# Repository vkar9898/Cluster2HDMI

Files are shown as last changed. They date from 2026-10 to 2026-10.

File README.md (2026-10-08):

# Cluster2HDMI
A project dedicated to utilising a 7 inch LCD panel as a standalone monitor via a HDMI-parallel RGB converter and a Pico 2 fitted on a custom PCB

I have been reverse engineering a 7" LCD panel that I pulled out of a vehicle dashboard, in hopes of using it as a standalone monitor. So far I have mapped every pin on the 45-pin video connector, and the next step is designing and ordering a PCB to drive it.

<p align="center">
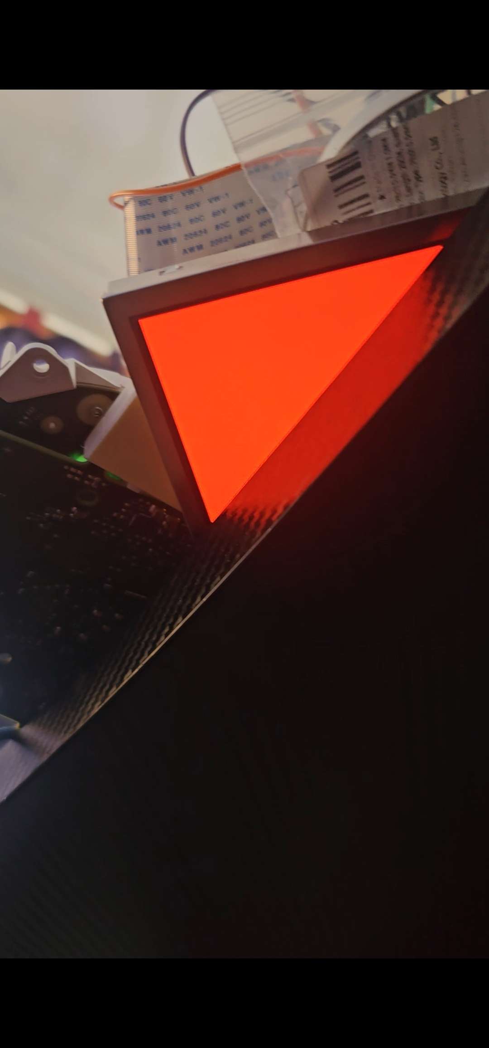
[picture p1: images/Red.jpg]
  
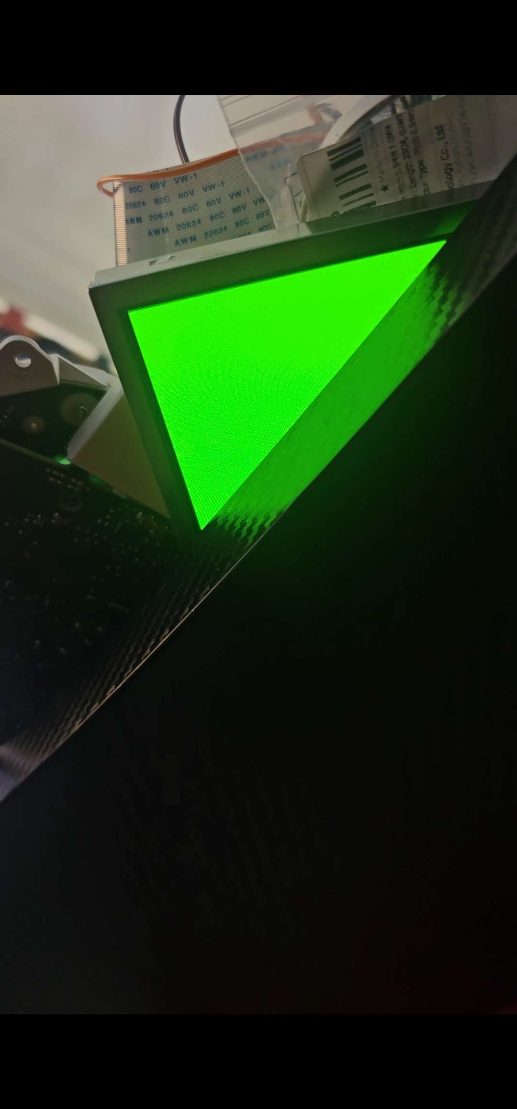
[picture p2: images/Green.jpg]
  
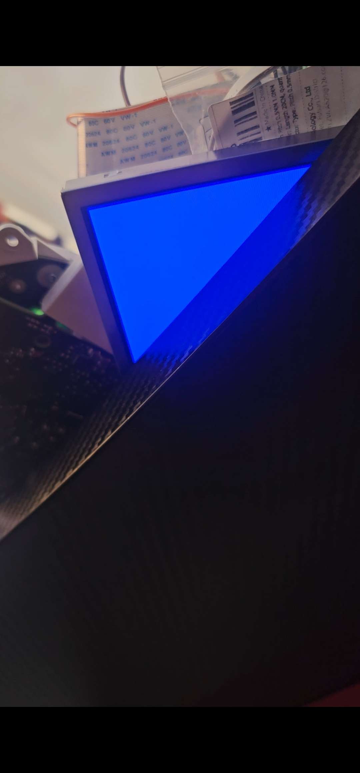
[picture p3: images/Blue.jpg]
  
</p>

<p align="center">
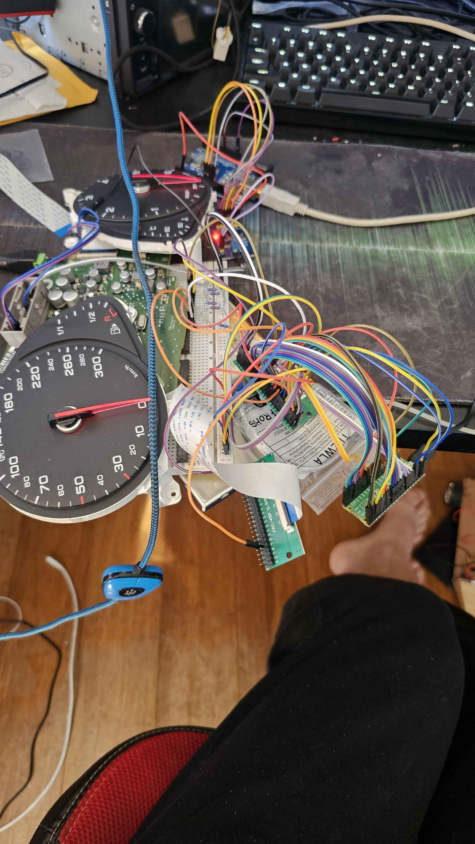
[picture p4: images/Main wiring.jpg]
  
</p>

## Why I made this

This panel comes from an Audi Q7 instrument cluster (dashboard). Prior to this, I was able to control the entire dashboard via the CAN protocol. After that, I had the dream of being able to control the LCD entirely independently. I have always found it interesting reverse engineering things and making them work how I want, so I believed this project would be a great start, and so far it has.

## What it does

In the end, I aim to have this work as a standalone monitor, working via converting HDMI to parallel RGB, with a 12V PSU powering both the panel and its backlight, and rerouting specific pins to the panel, in order to make it work.

## How it works

From my computer, a HDMI cable will be plugged into a custom PCB, where it is converted to parallel RGB, before the video-specific pins (RGB, HSYNC, VSYNC, PCLK, etc.) will be routed to the correct pins connected to the panel. A Pico 2 will replicate the SPI setup commands the dashboard originally sends to the panel, and control the backlight brightness. The 12V supply will also power the panel's logic through a 3.3V regulator, and the backlight through a constant-current LED driver.

## Reverse engineering the panel

Originally, I had tried to search for datasheets available for my panel, but this was to no avail. There is not a single public datasheet available on the internet, which meant I had to reverse engineer it myself entirely. I began by connecting the dashboard's ribbon to one FFC breakout board and the panel's flex to another, with jumper wires between them, so I could probe every pin for continuity and voltage with a multimeter while the panel was running. Many problems were met here, more in the [journal](JOURNAL.md).

### Pin map (45-pin, 0.5 mm FPC)

Numbers are the breakout board labels.

| Label | Function | Notes |
|---|---|---|
| 1, 2, 13, 22, 31, 33, 37, 44, 45 | Ground | |
| 3 | Unknown | 1.5 kΩ pull-down to ground on the cluster side |
| 4, 38 | Power in | Supplied by the cluster (voltage to be confirmed) |
| 5–12 | Blue B0–B7 | 5 = least significant bit |
| 14–21 | Green G0–G7 | 14 = least significant bit |
| 23–30 | Red R0–R7 | 23 = least significant bit |
| 32 | PCLK | Pixel clock |
| 34 | HSYNC | |
| 35 | VSYNC | |
| 36 | DE | Data enable |
| 39, 43 | Not connected | Function unknown |
| 40 | SPI data (MOSI) | Setup commands |
| 41 | SPI chip select | Active low |
| 42 | SPI clock | |

### Video timing (measured from the cluster)

| | Value |
|---|---|
| Resolution | 800 × 480 |
| Pixel clock | ~26.8 MHz (cluster), 25 MHz (my Pico driver) |
| Horizontal | HSYNC 10 px, back porch 6 px, active 800 px, front porch 106 px, total 922 px |
| Vertical | active 480 lines, front porch 8, VSYNC 4, back porch 8, total 500 lines |
| Refresh rate | ~58 Hz (cluster), ~54 Hz (Pico) |
| Sync polarity | HSYNC and VSYNC active low, DE active high |

### SPI setup sequence

3-wire SPI, mode 0, MSB first, ~500 kHz, chip select active low.
Starts ~25 ms after video starts. Without it the panel stays black.

| Step | Bytes (hex) | Delay after |
|---|---|---|
| 1 | 1B 50 00 | 2.15 ms |
| 2 | 1D 5C 00 | 2.15 ms |
| 3 | 10 00 | 2.15 ms |
| 4 | 08 80 | ~125.6 ms |
| 5 | 14 80 | |

The cluster repeats the whole set every ~545.6 ms. What each register does is unknown.

## Current status

Currently, I am able to display full-screen solid colours on the panel from the Pico: red, green and blue, as well as other colours such as cyan, magenta, white, etc. (6 bits per colour). The panel's power and backlight still come from the cluster. Next is to properly power the panel via my own power supply from a custom PCB, and be able to use it as a standalone monitor connected to my computer via HDMI.

## Wiring (current test setup)

Breakout A = panel side, Breakout B = cluster side. Numbers are the breakout labels.

### Timing and SPI

| Pico 2 | Breakout A | Signal |
|---|---|---|
| GP0 | 32 | PCLK |
| GP1 | 36 | DE |
| GP2 | 34 | HSYNC |
| GP27 | 35 | VSYNC |
| GP28 | — | Not connected (used internally by the Pico) |
| GP21 | 42 | SPI clock |
| GP22 | 40 | SPI data (MOSI) |
| GP26 | 41 | SPI chip select |
| GND | Ground rail | Ground |

### Colour data (top 6 bits of each colour)

| Colour | Bit | Breakout A | Pico 2 |
|---|---|---|---|
| Blue | B2 | 7 | GP5 |
| Blue | B3 | 8 | GP6 |
| Blue | B4 | 9 | GP7 |
| Blue | B5 | 10 | GP8 |
| Blue | B6 | 11 | GP3 |
| Blue | B7 | 12 | GP9 |
| Green | G2 | 16 | GP12 |
| Green | G3 | 17 | GP13 |
| Green | G4 | 18 | GP14 |
| Green | G5 | 19 | GP4 |
| Green | G6 | 20 | GP15 |
| Green | G7 | 21 | GP10 |
| Red | R2 | 25 | GP18 |
| Red | R3 | 26 | GP19 |
| Red | R4 | 27 | GP20 |
| Red | R5 | 28 | GP11 |
| Red | R6 | 29 | GP16 |
| Red | R7 | 30 | GP17 |

### Resistors to ground

| Breakout A | Resistor | Why |
|---|---|---|
| 3 | 1 kΩ | Stands in for the cluster's 1.5 kΩ pull-down |
| 5, 6 | 2.2 kΩ each | Blue B0–B1 held low (unused) |
| 14, 15 | 2.2 kΩ each | Green G0–G1 held low (unused) |
| 23, 24 | 2.2 kΩ each | Red R0–R1 held low (unused) |

### Cluster to panel (breakout B → breakout A)

| Connection | Purpose |
|---|---|
| B4 → A4 | Panel power from the cluster |
| B38 → A38 | Panel power from the cluster |
| A1, 2, 13, 22, 31, 33, 37, 44, 45 → ground rail | Panel grounds |
| B1, 22, 44 → ground rail | Cluster ground |
| A39, A43 | Left unconnected |
| 10-pin backlight ribbon | Stays plugged into the cluster |

Power order: cluster on first, then plug in the Pico.

## Hardware

Coming once PCB is designed

## Firmware

Currently, the Pico code is MicroPython, written and run through Thonny. It generates the timing signals (PCLK, HSYNC, VSYNC, DE) using the Pico's PIO hardware, sends the SPI setup sequence, and controls the red, green and blue bits. The test firmware was written with help from Claude (AI). In the future, it will only be doing the SPI sequence and backlight control on the PCB, as the HDMI-parallel RGB converter will be responsible for the timing and colour bits. Code can be found [here](Firmware)

## How to flash

1. Holding BOOTSEL, plug in your Pico, and drag the [MicroPython .uf2 file](https://micropython.org/download/RPI_PICO2/) onto the drive that appears.
2. Open Thonny and choose the Pico as the interpreter, before saving the [firmware](Firmware) file onto the Pico as "main.py". After this, it'll run automatically on power-up. 
3. Turn on the cluster first, then turn on the Pico. You are done!

## Known issues

* Pins 3, 39 and 43's functions are unknown
* Exactly what each SPI register does is unknown, but easily replicable
* Unknown whether the panel needs SPI commands repeated
* Panel's power and backlight still come from the cluster
* 10-pin backlight connector hasn't been reverse-engineered yet
* Pico test driver uses 6 bits per colour, not 8, and can only show solid colours
* Loose wiring can cause unexpected disconnections

## Building one yourself

Coming once the PCB is finished.

## Bill of materials

| Part | Qty | Est. cost (AUD) | Link | Description |
|---|---|---|---|---|
| **Main parts** | | | | |
| Adafruit TFP401 HDMI/DVI decoder (no touch) | 1 | 55 | [Adafruit](https://www.adafruit.com/product/2219) | Converts HDMI to 24-bit parallel RGB |
| PCB fabrication + assembly of FPC connectors | 1 order | 30–50 | [JLCPCB](https://jlcpcb.com) | Custom adapter/driver board |
| 12 V power supply | 1 | 33 | [Amazon](https://www.amazon.com.au/dp/B0CRGJ15HS) | Main power input |
| Raspberry Pi Pico 2 | 1 | owned | [Raspberry Pi](https://www.raspberrypi.com/products/raspberry-pi-pico-2/) | SPI setup commands + backlight control |
| Audi Q7 4M0 920 781 A instrument cluster | 1 | owned | [eBay](https://www.ebay.co.uk/itm/177800811902) | Source of the 7" 800×480 LCD panel |
| **Connectors** | | | | |
| Hirose FH34SRJ-45S-0.5SH 45-pin FPC connector | 2 | 5 | [LCSC C3170034](https://www.lcsc.com/product-detail/C3170034.html) | Panel connector |
| XUNPU FPC-05FB-40PH20 40-pin FPC connector | 2 | 5 | [LCSC C2856837](https://www.lcsc.com/product-detail/C2856837.html) | TFP401 ribbon connector |
| 40-pin 0.5 mm FFC cable, 100 mm, type A | 1 | 5 | [LCSC C2859463](https://www.lcsc.com/product-detail/C2859463.html) | TFP401 board to PCB |
| 10-pin FPC connector | 1 | 2 | [link] | Backlight connector (pitch to be confirmed) |
| DC-005 barrel jack | 1 | 1 | [LCSC C16214](https://www.lcsc.com/product-detail/C16214.html) | 12 V input |
| BOOMELE 1×20 2.54 mm female header | 2 | 2 | [LCSC C50984](https://www.lcsc.com/product-detail/C50984.html) | Socket for the Pico 2 |
| **12 V input protection** | | | | |
| TECHFUSE mSMD110-16V resettable fuse | 1 | 1 | [LCSC C69691](https://www.lcsc.com/product-detail/C69691.html) | 1.1 A, protects against shorts |
| SS34 Schottky diode | 1 | 1 | [LCSC C8678](https://www.lcsc.com/product-detail/C8678.html) | Reverse-polarity protection |
| **5 V supply** | | | | |
| TPS54202 buck converter | 1 | 1 | [LCSC C191884](https://www.lcsc.com/product-detail/C191884.html) | 12 V → 5 V for the TFP401 board and Pico |
| Sunlord SWPA6045S100MT 10 µH inductor | 1 | 1 | [LCSC C79272](https://www.lcsc.com/product-detail/C79272.html) | For the buck converter |
| 100 kΩ 1% 0805 resistor | 2 | <1 | [LCSC C149504](https://www.lcsc.com/product-detail/C149504.html) | Buck feedback (top) + MOSFET gate pull-down |
| 13 kΩ 1% 0805 resistor | 1 | <1 | [LCSC C17455](https://www.lcsc.com/product-detail/C17455.html) | Buck feedback (bottom), sets ~5.18 V |
| **3.3 V supply** | | | | |
| AMS1117-3.3 regulator | 1 | 1 | [LCSC C6186](https://www.lcsc.com/product-detail/C6186.html) | 3.3 V for the panel logic |
| **Capacitors (shared)** | | | | |
| 10 µF 25 V X5R 0805 capacitor | 4 | <1 | [LCSC C15850](https://www.lcsc.com/product-detail/C15850.html) | Buck input ×2, 3.3 V input, panel bypass |
| 22 µF 25 V X5R 0805 capacitor | 3 | <1 | [LCSC C45783](https://www.lcsc.com/product-detail/C45783.html) | Buck output ×2, 3.3 V output |
| 100 nF 50 V X7R 0805 capacitor | 3 | <1 | [LCSC C49678](https://www.lcsc.com/product-detail/C49678.html) | Buck input bypass, bootstrap, panel bypass |
| **Backlight driver** | | | | |
| TPS61169 LED driver | 1 | 2 | [LCSC C71045](https://www.lcsc.com/product-detail/C71045.html) | Boost driver for the backlight |
| Sunlord SWPA6045S220MT 22 µH inductor | 1 | 1 | [LCSC C83454](https://www.lcsc.com/product-detail/C83454.html) | For the LED driver |
| SS16 Schottky diode | 1 | 1 | [LCSC C84578](https://www.lcsc.com/product-detail/C84578.html) | For the LED driver |
| 4.7 µF 25 V X5R 0805 capacitor | 1 | <1 | [LCSC C1779](https://www.lcsc.com/product-detail/C1779.html) | LED driver input |
| 1 µF 50 V X7R 1206 capacitor | 1 | <1 | [LCSC C1848](https://www.lcsc.com/product-detail/C1848.html) | LED driver output |
| 5.1 Ω 1% 0805 resistor | 1 | <1 | [LCSC C17724](https://www.lcsc.com/product-detail/C17724.html) | Sets backlight current (~40 mA, to be confirmed) |
| NSI45020 constant-current regulator | 2 | 2 | [LCSC C129159](https://www.lcsc.com/product-detail/C129159.html) | One per LED string (may not be needed) |
| AO3400A MOSFET | 1 | 1 | [LCSC C20917](https://www.lcsc.com/product-detail/C20917.html) | PWM dimming (may not be needed) |
| **Panel signals** | | | | |
| 1.5 kΩ 1% 0805 resistor | 1 | <1 | [LCSC C4310](https://www.lcsc.com/product-detail/C4310.html) | Pin 3 pull-down, copies the cluster |
| 33 Ω 1% 0805 resistor | 1 | <1 | [LCSC C17634](https://www.lcsc.com/product-detail/C17634.html) | PCLK series resistor |
| **Indicator** | | | | |
| Green 0805 LED | 1 | <1 | [LCSC C2297](https://www.lcsc.com/product-detail/C2297.html) | Power indicator |
| 1 kΩ 1% 0805 resistor | 1 | <1 | [LCSC C17513](https://www.lcsc.com/product-detail/C17513.html) | LED current limit |
| **Total** | | **~150-175** (excl. owned parts and shipping) | | |

## Credits & references

- [LogicAnalyzer by gusmanb](https://github.com/gusmanb/logicanalyzer)
- [Adafruit TFP401 HDMI/DVI decoder](https://www.adafruit.com/product/2219)
- Claude (AI): helped write the test firmware and decode the logic analyser captures

## Licence

MIT, see [LICENSE](LICENSE).

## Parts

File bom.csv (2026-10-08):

Part | Qty | Est. cost (AUD) | Link | Description
Adafruit TFP401 HDMI/DVI decoder (no touch) | 1 | 55 | https://www.adafruit.com/product/2219 | Converts HDMI to 24-bit parallel RGB
PCB fabrication + assembly of FPC connectors | 1 order | 30-50 | https://jlcpcb.com | Custom adapter/driver board
12 V power supply | 1 | 33 | https://www.amazon.com.au/dp/B0CRGJ15HS | Main power input
Raspberry Pi Pico 2 | 1 | owned | https://www.raspberrypi.com/products/raspberry-pi-pico-2/ | SPI setup commands + backlight control
Audi Q7 4M0 920 781 A instrument cluster | 1 | owned | https://www.ebay.co.uk/itm/177800811902 | Source of the 7" 800×480 LCD panel
Hirose FH34SRJ-45S-0.5SH 45-pin FPC connector | 2 | 5 | https://www.lcsc.com/product-detail/C3170034.html | Panel connector
XUNPU FPC-05FB-40PH20 40-pin FPC connector | 2 | 5 | https://www.lcsc.com/product-detail/C2856837.html | TFP401 ribbon connector
40-pin 0.5 mm FFC cable, 100 mm, type A | 1 | 5 | https://www.lcsc.com/product-detail/C2859463.html | TFP401 board to PCB
10-pin FPC connector | 1 | 2 |  | Backlight connector (pitch to be confirmed)
DC-005 barrel jack | 1 | 1 | https://www.lcsc.com/product-detail/C16214.html | 12 V input
BOOMELE 1×20 2.54 mm female header | 2 | 2 | https://www.lcsc.com/product-detail/C50984.html | Socket for the Pico 2
TECHFUSE mSMD110-16V resettable fuse | 1 | 1 | https://www.lcsc.com/product-detail/C69691.html | 1.1 A, protects against shorts
SS34 Schottky diode | 1 | 1 | https://www.lcsc.com/product-detail/C8678.html | Reverse-polarity protection
TPS54202 buck converter | 1 | 1 | https://www.lcsc.com/product-detail/C191884.html | 12 V → 5 V for the TFP401 board and Pico
Sunlord SWPA6045S100MT 10 µH inductor | 1 | 1 | https://www.lcsc.com/product-detail/C79272.html | For the buck converter
100 kΩ 1% 0805 resistor | 2 | <1 | https://www.lcsc.com/product-detail/C149504.html | Buck feedback (top) + MOSFET gate pull-down
13 kΩ 1% 0805 resistor | 1 | <1 | https://www.lcsc.com/product-detail/C17455.html | Buck feedback (bottom), sets ~5.18 V
AMS1117-3.3 regulator | 1 | 1 | https://www.lcsc.com/product-detail/C6186.html | 3.3 V for the panel logic
10 µF 25 V X5R 0805 capacitor | 4 | <1 | https://www.lcsc.com/product-detail/C15850.html | Buck input ×2, 3.3 V input, panel bypass
22 µF 25 V X5R 0805 capacitor | 3 | <1 | https://www.lcsc.com/product-detail/C45783.html | Buck output ×2, 3.3 V output
100 nF 50 V X7R 0805 capacitor | 3 | <1 | https://www.lcsc.com/product-detail/C49678.html | Buck input bypass, bootstrap, panel bypass
TPS61169 LED driver | 1 | 2 | https://www.lcsc.com/product-detail/C71045.html | Boost driver for the backlight
Sunlord SWPA6045S220MT 22 µH inductor | 1 | 1 | https://www.lcsc.com/product-detail/C83454.html | For the LED driver
SS16 Schottky diode | 1 | 1 | https://www.lcsc.com/product-detail/C84578.html | For the LED driver
4.7 µF 25 V X5R 0805 capacitor | 1 | <1 | https://www.lcsc.com/product-detail/C1779.html | LED driver input
1 µF 50 V X7R 1206 capacitor | 1 | <1 | https://www.lcsc.com/product-detail/C1848.html | LED driver output
5.1 Ω 1% 0805 resistor | 1 | <1 | https://www.lcsc.com/product-detail/C17724.html | Sets backlight current (~40 mA, to be confirmed)
NSI45020 constant-current regulator | 2 | 2 | https://www.lcsc.com/product-detail/C129159.html | One per LED string (may not be needed)
AO3400A MOSFET | 1 | 1 | https://www.lcsc.com/product-detail/C20917.html | PWM dimming (may not be needed)
1.5 kΩ 1% 0805 resistor | 1 | <1 | https://www.lcsc.com/product-detail/C4310.html | Pin 3 pull-down, copies the cluster
33 Ω 1% 0805 resistor | 1 | <1 | https://www.lcsc.com/product-detail/C17634.html | PCLK series resistor
Green 0805 LED | 1 | <1 | https://www.lcsc.com/product-detail/C2297.html | Power indicator
1 kΩ 1% 0805 resistor | 1 | <1 | https://www.lcsc.com/product-detail/C17513.html | LED current limit
TOTAL |  | ~150-175 (excl. owned parts and shipping)

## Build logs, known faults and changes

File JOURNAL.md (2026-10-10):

---
title: "Cluster2HDMI"
author: "vkar9898"
description: "A project dedicated to utilising a 7 inch LCD panel from a car dashboard as a standalone monitor via a HDMI-parallel RGB converter and a Pico 2 fitted on a custom PCB."
created_at: "2026-10-07"
---

# October 7: Began reverse engineering

Started reverse engineering with the FFC cable misaligned by one pin, and didn't realise the mistake; spent a long time continuity checking and voltage metering to figure out the issue.

I began with basic voltage measuring, to ensure that my Pico wouldn't get fried when logic analysing (inputs must be under 3.3V). After concluding that all pins on the 45 pin connector were under or about 3.3V, I was ready to begin reverse engineering.

I did it 4 pins at a time, as this wasn't too messy and didn't get out of hand too easily. It also allowed more samples than doing most pins at once, which was a nice side benefit. Once I was able to set up the Pico 2 as an analyser with gusmanb's LogicAnalyzer, I was able to begin analysing by placing a jumper between GP0 and GP1 for triggering to work. Initially, when measuring, I deduced that PCLK was 31, HSYNC was 33, and DE was 35, with no VSYNC. I had assumed that VSYNC didn't exist on the panel and it used DE as a way of refreshing, and also failed to realise there was a setup sequence.

After the first logic analysing section, I moved onto continuity checking the panel itself, where I ran into many problems. The first problem was that the panel's FFC ribbon has two notches on its sides, while my breakout board doesn't have space for those notches. This resulted in a slightly angled FFC connection, which messed up many readings beyond pin 30. Pins such as 33 and 35 had continuity with ground, which is not possible. After realising this, I attempted to reseat the adapter many times, and ended up needing to cut notches in the breakout board specifically to fit the FFC.

After cutting notches, the FFC sat nicely in the breakout board, but then I ran into another problem. No matter how many times I reseated it, it was always 1 pin off my logic analysing. As it was already getting quite late, I decided to call it a day, and went to sleep.

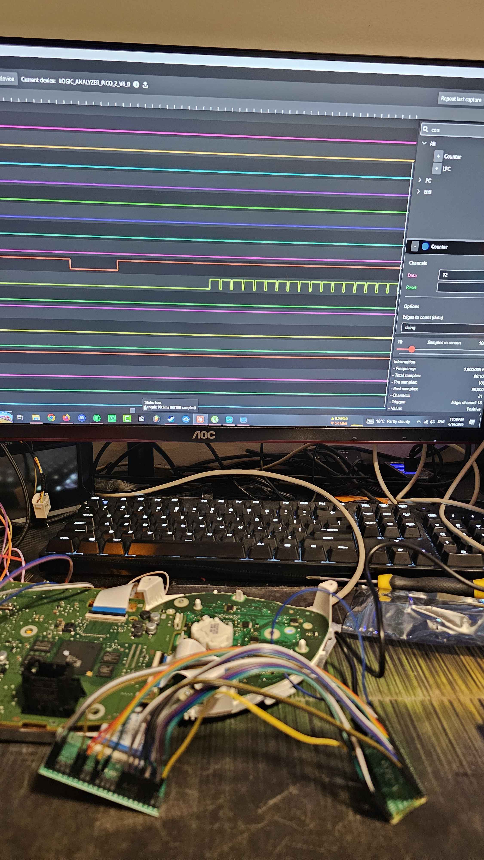
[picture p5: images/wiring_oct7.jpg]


**Total time spent: 6 hours**

# October 8: LCD works! But after a lot of tries

First, I began the day with continuity checking the cluster's FFC, and I couldn't believe my eyes. The pins perfectly matched the panel's FFC, which was very happy news. It was my initial logic analysing that had been off! With this newfound knowledge, I got the Pico 2 wired to the LCD, with the cluster supplying its 10-pin connector, and supplying power pins 4 and 38 through the cluster pins 4 and 38.

Here I ran into a problem. Screen turns on, backlight is on, but no colour. Nothing at all, the screen was entirely black. I was shocked, I believed I did everything right!

After contemplating, I decided to logic analyse again, on a fresh afternoon, with the FFC seated correctly. This time, I logic analysed all the pins that were showing low on October 7th captures. Bingo! I had found that pins 40, 41, and 42 were showing some sort of SPI sequence, so I decided to dig deeper. I thought using burst mode in the LogicAnalyzer app would help, but it didn't, and re-triggered instantly, giving tiny 200ns gaps, so I decided to switch to long captures. Here I was able to see the signal properly, see all of its timings correctly, and replicate it in MicroPython with the help of Claude. After getting the Pico 2 tediously wired to the LCD, the moment of truth was about to be shown...

And it did! The LCD glowed a blue-grey, signalling that there it was missing some green and most of its red. I decided to run a walk test with the slider tool, lighting one data pin at a time and noting its colour and brightness, which showed the strongest bits of each colour were the ones held low by resistors. I replaced six Pico wires off the weakest bits and onto the strongest bits, and moved the resistors onto the weakest bits, and I got all 3, red, green and blue! I was able to show a few different colours on the LCD, primarily red, green, blue, black, white, grey, cyan, magenta, and yellow. This was a huge win, so I decided to again call it a day, and proceed with the 10-pin connector another day.



**Total time spent: 5 hours**

# October 9: 10-pin connector testing, beginning to start designing custom PCB

Began testing the 10-pin connector for continuity and overall voltage. Found that pin 1, 4, 7, 10 are most likely unused (no continuity, no voltages, maybe sends signals back to the cluster?), 8, 9 function as LED + (~22.5V), 3, 5 and 6 are LED- (3V), and 2 is ground. The cluster reboots if the 10-pin isn't connected, so it probably has upstream and downstream pins. Currently thinking about how I design my own HDMI to parallel RGB adapter, using the TFP401APZPR microchip.

Picked out parts for my PCBA, and checked each LCSC number to ensure it's compatible with JLCPCB. Installed KiCad10 and easyeda2kicad, and imported some symbols and footprints from LCSC with it. Places teh wrong chip first, then swapped it for the right one, as the library path was wrong, so I had to import the footprint library manually.

Setup the TFP401, it's power, the 45-pin panel connector, HDMI input, EDID, and Pico 2 in a schematic. PCB design coming soon. Encountered some minor errors in KiCad, but fixed them easily.
Recording: https://lapse.hackclub.com/timelapse/lRLIcTCkxbhM (can't add two lapse files to Forge)

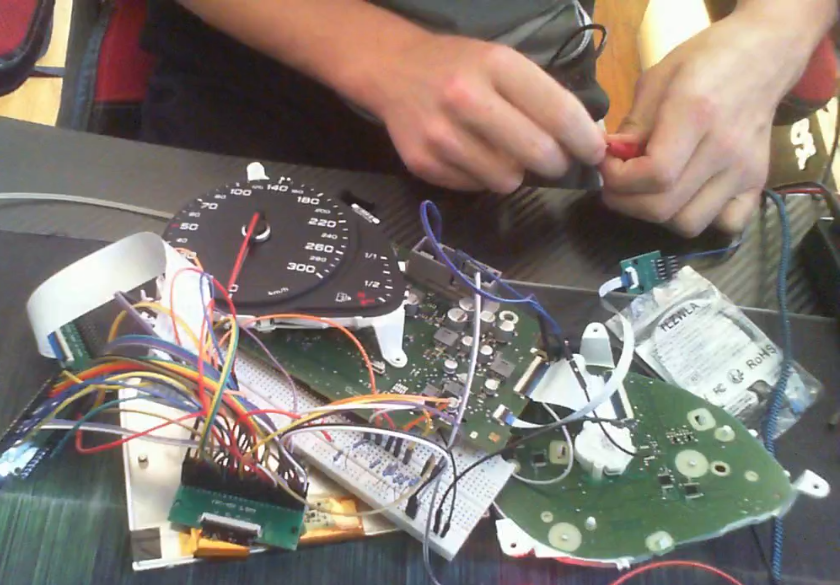
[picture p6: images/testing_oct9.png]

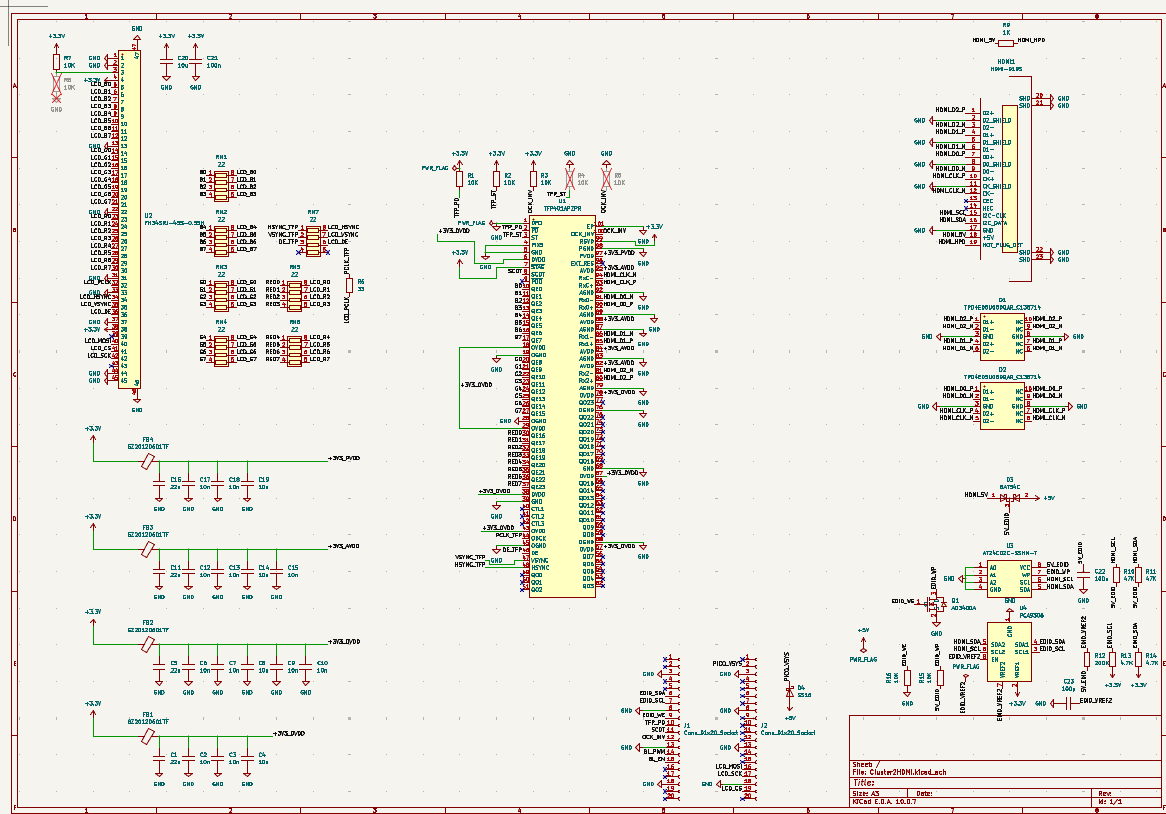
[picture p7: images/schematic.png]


**Total time spent: 4 hours**

# October 10: Finishing off PCB designing

Figured out how many layers to use on my board, decided to do 4 layers to allow for high speed HDMIS to pass through, with layers top/gnd/pwr/bottom. Calculated track width and gap for the HDMI pairs, worked out with JLC's impedance calculater (100 ohms), and set out a rule set for normal signals, power, and HDMI to make sure everything would work. 

Measured the LCD panel, and decided to build the board same width as it but a little shorter, to allow for a case later. The PCB will use two screws that are available on the current LCD, and allows the 45-pin pannel connector to slide in nicely, and the 10-pin connector to slide in well. Printed the PCB on paper to double-check everything lines up, everything did.

Next was deciding what placement to do, I decided to put HDMI socket on the top edge with the TFP401 under it. This minimises travel between the HDMI and the TFP401, and is also easy to me as I have a HDMI cable with a twisting mechanism. The Pico 2 will be placed in a socket top-right, USB pointing at the right edge (for coding). Figured the PSU would be nicest to be on the bottom right, and so its from the panels face, rather than an edge.

I ran into a few problems here too, mostly regarding pin orders and mirroring, specifically the HDMI socket's pins being mirrored relative to the TFP401's, to which the fix was copying Adafruit's TFP board: two pairs loop around under the socket, and two pairs swap over using vias. The 28 colour/sync/clock wires were also mirrored, which meant they'd have to cross over using vias through the bottom layer. 

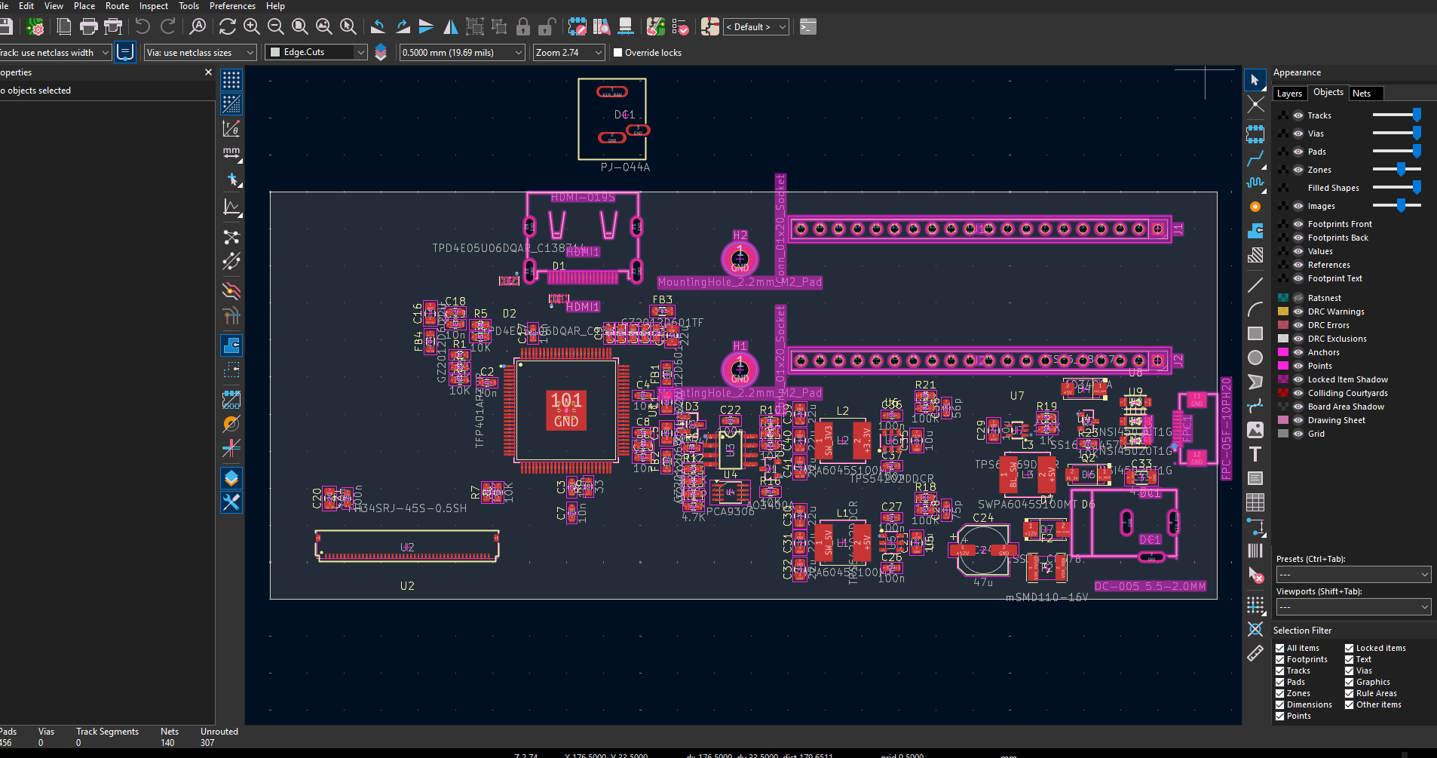
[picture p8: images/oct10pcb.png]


**Total time spent: 4 hours**

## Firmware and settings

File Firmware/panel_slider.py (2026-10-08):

# panel_slider.py  -  runs on your PC (Windows), not on the Pico.
# Steps through the panel's data pins one at a time over USB and says the
# label number out loud, so you can watch the panel from under the desk.
#
# Before running:
#   1. In Thonny, with the Pico connected, open audi_panel_test_v3.py and
#      File > Save as... > Raspberry Pi Pico > main_v3.py
#      (change PICO_MODULE below if you use a different name).
#   2. In Thonny: Run > Configure interpreter > "Local Python 3"
#      (this frees the Pico's USB port for this program).
#   3. Open this file in Thonny and press Run.
#      If it says pyserial is missing: Tools > Manage packages > pyserial.
#
# Keys: Left / Right arrows step through the pins, W = all white, B = all black,
#       D = colour demo.

import tkinter as tk
from tkinter import ttk, messagebox
import threading, time, ast, subprocess, sys

try:
    import serial
    import serial.tools.list_ports
except ImportError:
    print("pyserial is missing: in Thonny use Tools > Manage packages > pyserial")
    raise

PICO_VID = 0x2E8A
PICO_MODULE = "main_v3"   # file name on the Pico, without .py


def find_port():
    for p in serial.tools.list_ports.comports():
        if p.vid == PICO_VID:
            return p.device
    return None


def speak(text):
    if sys.platform != "win32":
        return
    cmd = ("Add-Type -AssemblyName System.Speech; "
           "(New-Object System.Speech.Synthesis.SpeechSynthesizer).Speak('%s')" % text)
    subprocess.Popen(["powershell", "-NoProfile", "-Command", cmd],
                     creationflags=getattr(subprocess, "CREATE_NO_WINDOW", 0))


class Pico:
    def __init__(self, port):
        self.s = serial.Serial(port, 115200, timeout=0.1)
        self.lock = threading.Lock()
        self.buf = ""
        threading.Thread(target=self._reader, daemon=True).start()
        time.sleep(0.3)
        self.send("")

    def _reader(self):
        while True:
            try:
                data = self.s.read(256)
            except Exception:
                return
            if data:
                self.buf = (self.buf + data.decode(errors="ignore"))[-4000:]

    def send(self, line):
        with self.lock:
            self.s.write((line + "\r").encode())

    def ask_labels(self):
        self.buf = ""
        self.send("print('LABELS', [l for g, l in DATA], [g for g, l in DATA])")
        end = time.time() + 3
        while time.time() < end:
            for row in self.buf.splitlines():
                if row.startswith("LABELS "):
                    parts = row[len("LABELS "):]
                    split = parts.index("] [") + 1
                    return ast.literal_eval(parts[:split]), ast.literal_eval(parts[split + 1:])
            time.sleep(0.05)
        return None, None


class App:
    def __init__(self, root):
        self.root = root
        root.title("Panel pin slider")
        port = find_port()
        if not port:
            messagebox.showerror("No Pico", "Couldn't find the Pico on USB.\n"
                                 "Is Thonny still connected to it? Switch Thonny to 'Local Python 3'.")
            root.destroy()
            return
        try:
            self.pico = Pico(port)
        except Exception as e:
            messagebox.showerror("Port busy", "Couldn't open %s:\n%s\n\nClose Thonny's "
                                 "connection to the Pico first." % (port, e))
            root.destroy()
            return
        self.pico.send("from %s import *" % PICO_MODULE)
        time.sleep(2)
        self.labels, self.gps = self.pico.ask_labels()
        if not self.labels:
            messagebox.showerror("No answer", "The Pico didn't answer.\nIs %s.py saved on it, " % PICO_MODULE +
                                 "and did it finish starting? Try unplugging and replugging the Pico.")
            root.destroy()
            return

        self.speak_on = tk.BooleanVar(value=True)
        self.idx = tk.IntVar(value=0)

        top = ttk.Frame(root, padding=10)
        top.pack(fill="x")
        ttk.Label(top, text="Connected on %s" % port).pack(side="left")
        ttk.Checkbutton(top, text="Speak label", variable=self.speak_on).pack(side="right")

        self.big = tk.Label(root, text="", font=("Segoe UI", 40, "bold"))
        self.big.pack(pady=10)

        self.scale = tk.Scale(root, from_=0, to=len(self.labels) - 1, orient="horizontal",
                              length=600, showvalue=False, variable=self.idx,
                              command=lambda v: self.show(int(float(v))))
        self.scale.pack(padx=20)

        btns = ttk.Frame(root, padding=10)
        btns.pack()
        ttk.Button(btns, text="< Prev", command=lambda: self.step(-1)).pack(side="left", padx=4)
        ttk.Button(btns, text="Next >", command=lambda: self.step(1)).pack(side="left", padx=4)
        ttk.Button(btns, text="All white", command=self.white).pack(side="left", padx=4)
        ttk.Button(btns, text="All black", command=self.black).pack(side="left", padx=4)
        ttk.Button(btns, text="Resend setup", command=lambda: self.pico.send("send_setup()")).pack(side="left", padx=4)

        cols = ttk.Frame(root, padding=(10, 0))
        cols.pack()
        for name in ("red", "green", "blue", "yellow", "cyan", "magenta", "grey"):
            ttk.Button(cols, text=name.capitalize(),
                       command=lambda n=name: self.colour(n)).pack(side="left", padx=3)
        ttk.Button(cols, text="Demo", command=self.demo).pack(side="left", padx=3)

        notes = ttk.LabelFrame(root, text="Notes per pin (colour + brightness)", padding=10)
        notes.pack(fill="both", expand=True, padx=10, pady=10)
        self.entries = []
        for i, (lab, gp) in enumerate(zip(self.labels, self.gps)):
            r, c = i % 9, (i // 9) * 2
            ttk.Label(notes, text="Label %d (GP%d)" % (lab, gp)).grid(row=r, column=c, sticky="w", padx=4)
            e = ttk.Entry(notes, width=18)
            e.grid(row=r, column=c + 1, padx=4, pady=1)
            self.entries.append(e)
        ttk.Button(root, text="Copy notes to clipboard", command=self.copy_notes).pack(pady=(0, 10))

        root.bind("<Left>", lambda e: self.step(-1))
        root.bind("<Right>", lambda e: self.step(1))
        root.bind("<Key-w>", lambda e: self.white())
        root.bind("<Key-b>", lambda e: self.black())
        root.bind("<Key-d>", lambda e: self.demo())
        self.show(0)

    def show(self, i):
        lab, gp = self.labels[i], self.gps[i]
        self.idx.set(i)
        self.big.config(text="Label %d   (GP%d)   %d/%d" % (lab, gp, i + 1, len(self.labels)))
        self.pico.send("only(%d)" % lab)
        if self.speak_on.get():
            speak("label %d" % lab)

    def step(self, d):
        i = max(0, min(len(self.labels) - 1, self.idx.get() + d))
        self.show(i)

    def white(self):
        self.big.config(text="ALL WHITE")
        self.pico.send("white()")
        if self.speak_on.get():
            speak("white")

    def black(self):
        self.big.config(text="ALL BLACK")
        self.pico.send("black()")
        if self.speak_on.get():
            speak("black")

    def colour(self, name):
        self.big.config(text=name.upper())
        self.pico.send("%s()" % name)
        if self.speak_on.get():
            speak(name)

    def demo(self):
        self.big.config(text="DEMO")
        self.pico.send("demo()")

    def copy_notes(self):
        text = "\n".join("Label %d (GP%d): %s" % (lab, gp, e.get())
                         for lab, gp, e in zip(self.labels, self.gps, self.entries))
        self.root.clipboard_clear()
        self.root.clipboard_append(text)
        messagebox.showinfo("Copied", "Notes copied - paste them into the chat.")


if __name__ == "__main__":
    root = tk.Tk()
    App(root)
    root.mainloop()

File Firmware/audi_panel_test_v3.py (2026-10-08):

# audi_panel_test_v3.py
# Pico 2 (RP2350) + MicroPython
# Audi Q7 4M cluster LCD (800x480 parallel RGB) - timing + SPI setup + colour.
#
# New in v3: the Pico now drives the TOP 6 bits of each colour (it had the
# bottom bits before, and the top bits were held low - that's why white
# looked blue-grey). Colour bit layout, confirmed by the slider walk:
#   Blue  = labels 5..12  (5 = weakest bit, 12 = strongest)
#   Green = labels 14..21
#   Red   = labels 23..30
#
# Save on the Pico as main_v3.py (or main.py so it starts by itself).
# Shell commands:
#   white()  black()  rgb(r, g, b)   (0-255 each, e.g. rgb(255, 128, 0) = orange)
#   red() green() blue() yellow() cyan() magenta() grey()
#   demo()                cycle through the colours, 2 s each
#   only(label)  label(label, 0/1)  walk()
#   send_setup()  auto_refresh(False/True)  stop()
#
# ---------------------------------------------------------------
# WIRING (Pico 2 GPIO -> breakout A label)
#   GP0  -> 32  PCLK
#   GP1  -> 36  DE
#   GP2  -> 34  HSYNC
#   GP27 -> 35  VSYNC
#   GP28 -> NOTHING (internal flag)
#   GP21 -> 42  SPI clock
#   GP22 -> 40  SPI data
#   GP26 -> 41  SPI chip select
#   GP3..GP20 -> data labels, see DATA below
#   1k to ground on: A3 2.2k to A5, A6, A14, A15, A23, A24
#   GND  -> ground rail
# Power order: cluster ON first, then plug in the Pico and press Run.
# ---------------------------------------------------------------

import rp2
import machine
from machine import Pin, Timer
import micropython
import time

PCLK_GP  = 0
DE_GP    = 1
HSYNC_GP = 2
VSYNC_GP = 27
VACT_GP  = 28

SPI_SCK_GP  = 21   # -> label 42
SPI_MOSI_GP = 22   # -> label 40
SPI_CS_GP   = 26   # -> label 41

# (Pico GPIO, breakout label) - top 6 bits of each colour, weakest first
BLUE_BITS  = [(5, 7), (6, 8), (7, 9), (8, 10), (3, 11), (9, 12)]
GREEN_BITS = [(12, 16), (13, 17), (14, 18), (4, 19), (15, 20), (10, 21)]
RED_BITS   = [(18, 25), (19, 26), (20, 27), (11, 28), (16, 29), (17, 30)]
DATA = BLUE_BITS + GREEN_BITS + RED_BITS

# ---- setup commands captured from the cluster ----------------
SETUP_GROUP = [
    bytes([0x1B, 0x50, 0x00]),
    bytes([0x1D, 0x5C, 0x00]),
    bytes([0x10, 0x00]),
    bytes([0x08, 0x80]),
]
GROUP_GAP_US  = 2150          # gap between the four commands
LATE_CMD      = bytes([0x14, 0x80])
LATE_DELAY_MS = 126           # sent ~125.6 ms after the group
REPEAT_MS     = 546           # whole set repeats every ~545.6 ms

# ---- timing ---------------------------------------------------
PIO_FREQ = 50_000_000     # 25 MHz pixel clock
H_ACTIVE = 800
H_FP     = 106
V_ACTIVE = 480


@rp2.asm_pio(sideset_init=rp2.PIO.OUT_LOW,
             set_init=(rp2.PIO.OUT_LOW, rp2.PIO.OUT_HIGH))
def htiming():
    pull()                .side(0)
    mov(y, osr)           .side(0)
    pull()                .side(0)
    wrap_target()
    set(pins, 0)          .side(0)
    set(x, 8)             .side(1)
    label("hs")
    nop()                 .side(0)
    jmp(x_dec, "hs")      .side(1)
    set(pins, 2)          .side(0)
    set(x, 3)             .side(1)
    label("bp")
    nop()                 .side(0)
    jmp(x_dec, "bp")      .side(1)
    mov(x, osr)           .side(0)
    jmp(pin, "act")       .side(1)
    set(pins, 2)          .side(0)
    jmp("px")             .side(1)
    label("act")
    set(pins, 3)          .side(0)
    nop()                 .side(1)
    label("px")
    nop()                 .side(0)
    jmp(x_dec, "px")      .side(1)
    set(pins, 2)          .side(0)
    mov(x, y)             .side(1)
    label("fp")
    nop()                 .side(0)
    jmp(x_dec, "fp")      .side(1)
    wrap()


@rp2.asm_pio(sideset_init=(rp2.PIO.OUT_HIGH, rp2.PIO.OUT_LOW))
def vtiming():
    pull()                .side(1)
    wrap_target()
    wait(1, gpio, 2)      .side(1)
    wait(0, gpio, 2)      .side(1)
    mov(x, osr)           .side(3)
    label("a")
    wait(1, gpio, 2)      .side(3)
    wait(0, gpio, 2)      .side(3)
    jmp(x_dec, "a")       .side(3)
    wait(1, gpio, 2)      .side(3)
    wait(0, gpio, 2)      .side(3)
    set(x, 6)             .side(1)
    label("f")
    wait(1, gpio, 2)      .side(1)
    wait(0, gpio, 2)      .side(1)
    jmp(x_dec, "f")       .side(1)
    wait(1, gpio, 2)      .side(1)
    wait(0, gpio, 2)      .side(1)
    set(x, 2)             .side(0)
    label("s")
    wait(1, gpio, 2)      .side(0)
    wait(0, gpio, 2)      .side(0)
    jmp(x_dec, "s")       .side(0)
    wait(1, gpio, 2)      .side(0)
    wait(0, gpio, 2)      .side(0)
    set(x, 6)             .side(1)
    label("b")
    wait(1, gpio, 2)      .side(1)
    wait(0, gpio, 2)      .side(1)
    jmp(x_dec, "b")       .side(1)
    wrap()


# ---- SPI (bit-banged, mode 0: data set while clock low, read on rising edge)
spi_cs   = Pin(SPI_CS_GP, Pin.OUT, value=1)
spi_sck  = Pin(SPI_SCK_GP, Pin.OUT, value=0)
spi_mosi = Pin(SPI_MOSI_GP, Pin.OUT, value=0)

def spi_write(frame):
    spi_cs(0)
    for byte in frame:
        for bit in range(7, -1, -1):
            spi_mosi((byte >> bit) & 1)
            spi_sck(1)
            spi_sck(0)
    spi_mosi(0)
    spi_cs(1)

def send_group():
    for f in SETUP_GROUP:
        spi_write(f)
        time.sleep_us(GROUP_GAP_US)

def send_setup():
    send_group()
    time.sleep_ms(LATE_DELAY_MS)
    spi_write(LATE_CMD)
    print("setup commands sent")

_t_cycle = Timer()
_t_late = Timer()

def _late(_):
    spi_write(LATE_CMD)

def _cycle_sched(_):
    send_group()
    _t_late.init(mode=Timer.ONE_SHOT, period=LATE_DELAY_MS,
                 callback=lambda t: micropython.schedule(_late, 0))

def auto_refresh(on=True):
    if on:
        _t_cycle.init(mode=Timer.PERIODIC, period=REPEAT_MS,
                      callback=lambda t: micropython.schedule(_cycle_sched, 0))
        print("auto refresh on (every %d ms)" % REPEAT_MS)
    else:
        _t_cycle.deinit()
        _t_late.deinit()
        print("auto refresh off")


# ---- start video ----------------------------------------------
data_pins = [Pin(gp, Pin.OUT, value=0) for gp, _ in DATA]
by_label = {lab: data_pins[i] for i, (_, lab) in enumerate(DATA)}

sm_v = rp2.StateMachine(4, vtiming, freq=machine.freq(),
                        sideset_base=Pin(VSYNC_GP))
sm_h = rp2.StateMachine(0, htiming, freq=PIO_FREQ,
                        sideset_base=Pin(PCLK_GP),
                        set_base=Pin(DE_GP),
                        jmp_pin=Pin(VACT_GP))
sm_v.put(V_ACTIVE - 2)
sm_h.put(H_FP - 2)
sm_h.put(H_ACTIVE - 2)
sm_v.active(1)
sm_h.active(1)


# ---- helpers --------------------------------------------------
def white():
    for p in data_pins:
        p.value(1)

def black():
    for p in data_pins:
        p.value(0)

def label(lab, v):
    by_label[lab].value(1 if v else 0)

def only(lab):
    black()
    label(lab, 1)
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

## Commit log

2026-10-08 Enhance README with project details and specifications
    Expanded README with detailed project description, reverse engineering process, hardware specifications, firmware information, and current status of the LCD panel project.
2026-10-08 Update README with wiring and flashing instructions
    Added wiring details, timing, and flashing instructions for Pico setup.
2026-10-08 Add .gitkeep to bom.csv
    [bom.csv]
2026-10-08 Enhance README with technical details and BOM
    Updated the README to include video timing, SPI setup sequence, current status, and bill of materials with detailed parts and costs.
2026-10-08 Revise flashing instructions and update BOM prices
    Updated firmware file name to 'main.py' in flashing instructions and added price for 12 V power supply.
2026-10-08 Add bill of materials (BOM) for project
    Added bill of materials (BOM) for the project, detailing parts, quantities, estimated costs, links, and descriptions.
    [bom.csv]
2026-10-08 Revise October 8 journal entry on LCD setup
    Updated the description of the LCD wiring process and troubleshooting steps.
2026-10-08 Update resistor value comment in audi_panel_test_v3.py
2026-10-08 Revise BOM with new parts and formatting fixes
    Updated the bill of materials (BOM) to include new parts and corrected formatting.
    [bom.csv]
2026-10-08 Update bom.csv to include new components and costs
    [bom.csv]
2026-10-09 Enhance October 9 journal entry with more details
    Updated the journal entry for October 9 with additional details about the 10-pin connector testing, PCB design process, and parts selection.
2026-10-10 Update JOURNAL.md with PCB design progress
    Documented progress on PCB design, including layer decisions, measurements, and component placements. Addressed issues with pin orders and mirroring for HDMI socket connections.
2026-10-11 Update JOURNAL.md with October 11 entry
    Added a new entry for October 11 detailing the completion of PCB design.
2026-10-12 Revise README with hardware, firmware, and BOM updates
    Updated hardware and firmware sections, added details about the Pico 2 pin connections, and clarified the building instructions. Revised the bill of materials with updated costs and sources.
2026-10-12 Revise README with project updates and BOM details
    Updated project status and added new images and cost details.
2026-10-12 Revise README with project and Pico 2 details
    Updated project description and details about the Pico 2 functionality.
2026-11-04 Revise BOM with updated prices and new entries
    Updated prices and descriptions for various items in the BOM, including shipping estimates and discounts.
2026-11-04 Fix entries for shipping and screws in bom.csv
    Updated shipping and screw entries with corrected descriptions.
